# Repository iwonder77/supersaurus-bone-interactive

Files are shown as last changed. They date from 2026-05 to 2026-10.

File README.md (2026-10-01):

# Supersaurus Bone Interactive

Three-channel 555 monostable timer board driving RGB LED strips for a guess-the-dinosaur-bone exhibit at Thanksgiving Point's Museum of Ancient Life.

https://github.com/user-attachments/assets/5193e17a-1725-41bf-98e3-4b2cfe211b8b

---

## At a Glance

| | |
| --- | --- |
| **Supply** | 12 V DC, single rail |
| **Channels** | 3 (one per answer slot) |
| **Input per channel**  | Littlefuse reed switch (slot occupancy) AND master pushbutton |
| **Output pulse width** | `~3.63s` - set by R`33k` / C`100uF` |
| **Load per channel** | 12V RGB LED strip, 1.67 A measured |
| **Load switching** | Off-board N-channel MOSFET module, low-side |
| **PCB** | `2-layer, 1 oz copper, HASL, 1.6 mm` |
| **Assembly** | `JLCPCB Assembly and hand soldered` |
| **Active logic** | Trigger is active-LOW; LED output is active-HIGH |

---

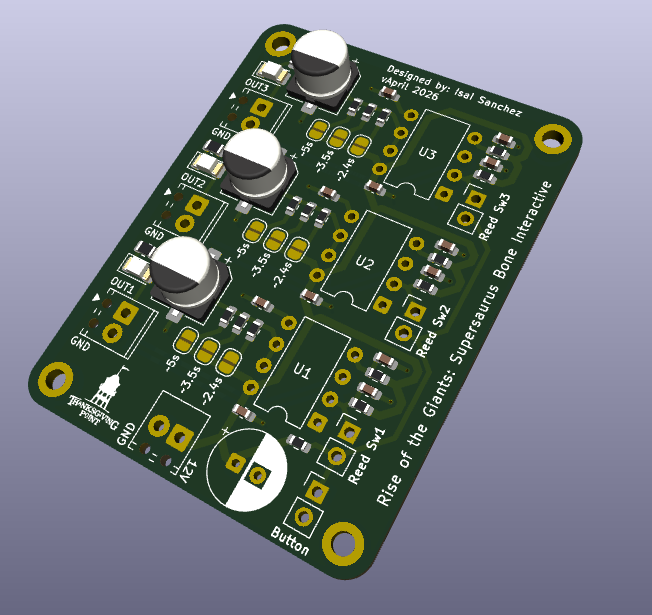
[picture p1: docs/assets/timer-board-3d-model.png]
3d PCB Model


## Overview

The Supersaurus bone interactive at Thanksgiving Point's Museum of Ancient Life invites visitors to guess which dinosaur the Supersaurus is related to based solely on scapula bone graphics. Guests place the Supersaurus scapula into one of three slots, each corresponding to a different dinosaur with its own scapula graphic. When they're ready to check their answer, they press a button, and an LED light strip installed behind the frosted acrylic slots briefly lights up red or green, providing immediate feedback on their guess.

When presented with the requirements of this project, my mind immediately jumped to using basic GPIO pins on a microcontroller to read the inputs, debounce them in software, and trigger a switching module for the lights. Even though that may have worked, removing software entirely for a three-input interaction with fixed timing removes an entire set of failure modes. A discrete analog implementation has no boot time, no watchdog to tune, and no flash to corrupt on abrupt power loss.

## Hardware Design Requirements

The interactive needed a circuit that:

- Debounces reed switch + button inputs for a smooth user experience
- Triggers immediate feedback on their answer for a short duration
- Resets the system quickly to not spoil the answer for the next guest
- Draws minimal power to handle reliable long term operation (next to 0 maintenance on parts)

These requirements quickly led to using a 555 timer in monostable mode to handle the timing portion of the interactive, and a MOSFET circuit to handle the fast and power efficient switching of a higher current load (LED strips).

## Main Hardware Components

- T.I. NE555P Timer ([datasheet](https://www.ti.com/lit/ds/symlink/ne555.pdf?ts=1777883502652))
- IRF520 MOSFET ([datasheet](https://www.vishay.com/docs/91017/irf520.pdf))
- PWM RGB LED Strips [link](https://www.amazon.com/dp/B0FSWXXXD4?ref=fed_asin_title&th=1)

The full BOM is included in the `manufacturing/` folder

## Full Schematic

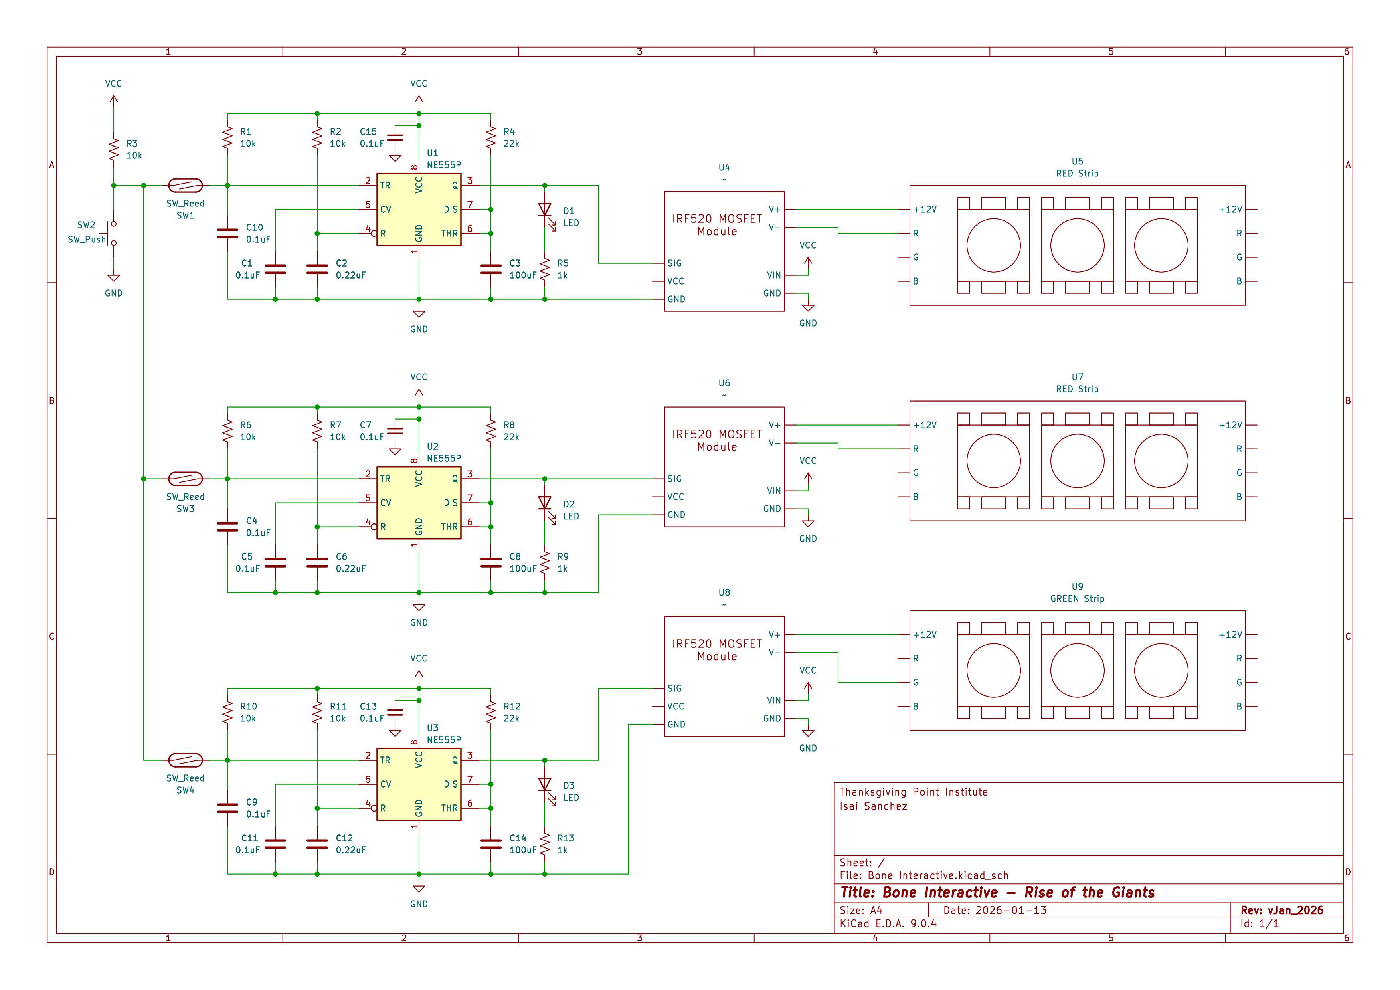
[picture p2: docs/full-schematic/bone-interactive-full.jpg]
full schematic


## Main Hardware Architecture

Each 555 timer's TRIG pin is connected to a single reed switch (mounted behind the slot guests put the bone in), and each reed switch feeds into one "master" N.O. button. RC/pull up networks are configured for each TRIG pin to ensure smooth and predictable switching. This configuration allows the TRIG pin on each 555 timer to be pulled LOW only when its corresponding reed switch is closed **and** the button is pressed.

The three 555 timers are used in monostable mode to output a short pulse signal on pin Q when the TRIG pin is pulled low. More on monostable mode and the duration of the pulse below. The output signal (~10.3V when VCC = 12V) is fed into the gate of a IRF520 N-channel MOSFET module, which switches the low side of an RGB LED Strip for as long as the gate is driven.

## 555 Timer Notes

### Monostable Mode

Shorting the DISCHARGE and THRESHOLD pins of the 555 timer and routing them to an RC circuit operates the 555 timer in monostable mode. Ben Eater has a really great and informative series on the different 555 timer modes, I highly recommend watching them. Here's the one about [monostable mode](https://www.youtube.com/watch?v=81BgFhm2vz8).

In any case, the formula for the output signal duration is

$$
t_w = 1.1 \times R_A \times C
$$

Where $R_A$ and $C$ are the values of the resistor and capacitor. For future boards I wanted to make this duration configurable by having three open jumpers routed to resistors of different values (22k, 33k, 47k). The output pulse duration would change depending on which jumper is soldered.

Note: the trigger pulse must be shorter than $t_w$ and below $\frac{1}{3}V_{CC}$ (the 555's internal comparator threshold). If TRIG remains below $\frac{1}{3}V_{CC}$ beyond $t_w$, the output holds HIGH until TRIG rises.

### Power-on Reset Circuit

The 0.22uF and 10k RC network on the 555's RESET pin form a POR (power-on reset) circuit. During initial power-up testing without it, the output (Q) pin produced occasional HIGH pulses due to undefined internal states of the IC, which turned on downstream LED strips. This RC network briefly holds RESET low during power-up, forcing Q in a known LOW state while internal circuitry stabilizes. As the 0.22uF capacitor charges, RESET rises to VCC and normal operation begins, preventing false triggering at startup.

### Output (Q) Voltage

When triggered, the output voltage on pin Q isn't necessarily equal to VCC. When powered by 5V, I measured outputs of ~3.3V. When powered by 12V, I measured outputs of ~10.3V. The datasheet confirms this slight drop in voltage, and it is important to know since we'll be using it to drive the gate of an N-Channel MOSFET.

## MOSFET Selection and Gate Drive Design Notes

### Role

The main design requirements that guided my MOSFET selection were the following

- Fast switch times of 12V RGB LED strip loads (on the order of 1-2A)
- Minimal power dissipation
- Predictable operating behavior

Although quite outdated, the IRF520 N-Channel MOSFET was initially selected due to its accessibility, very low cost, and basic matching of electrical characteristics to the requirements described above (more on these below).

### Initial Implementation and Failure Mode

My initial prototype powered the 555 timer at VCC = 5V and used the output (Q) pin to directly drive the gate of an IRF520 MOSFET module. While the timing circuit functioned correctly, the LED strip failed to illuminate properly. This failure mode was not due to wiring or logic errors, but rather improper gate drive conditions for the selected MOSFET.

I'll start off by describing the important electrical characteristics we should know about for this design (for a deeper dive, refer to the [datasheet](https://www.vishay.com/docs/91017/irf520.pdf)). Then I'll discuss the proper gate drive design.

### Key Electrical Considerations

#### 1. $V_{GS(th)}$ Gate-Source Threshold Voltage

$V_{GS(th)} = 2.0\,\text{V}$ to $4.0\,\text{V}$ at $I_D = 250\,\mu\text{A}$

This parameter defines the voltage at which the MOSFET just barely begins to conduct a very small current - it is **not** an operating point for driving the gate and turning on the MOSFET. The best design drives the gate well past this threshold simply due to the fact that at higher gate voltages, the resistance between the drain-source ($R_{DS(on)}$) is much lower, leading to more efficient power operation.

#### 2. $R_{DS(on)}$ Drain-Source "on" Resistance

$R_{DS(on)} = 0.27\,\Omega$ at $V_{GS} = 10\,\text{V}$

For switching applications, the MOSFET must operate in the **ohmic (linear) region** (the $I_D$ vs. $V_{DS}$ graph below shows this region for various $V_{GS}$ curves) with as low a $R_{DS(on)}$ as possible. The lower the resistance, the less power is dissipated. To reach this lower resistance, we must drive the gate further and further from the threshold voltage (but don't exceed its maximum).

#### 3. $I_D$ vs. $V_{DS}$ graph at T = 25C (from datasheet)

<div align="center">
    <image src="docs/assets/ID-vs-VDS-curve.png" alt="id-vs-vds-curve">
</div>

In the ohmic region (linear region of the curves) the MOSFET acts like a voltage controlled resistor, where

$$
I_D = \frac{V_{DS}}{R_{DS(on)}}
$$

note that $R_{DS(on)}$ is not a fixed quantity, but decreases as $V_{GS}$ rises above $V_{GS(th)}$. The datasheet value of $0.27\,\Omega$ only holds at $V_{GS} = 10V$. Near the threshold voltage, it can be orders of magnitude higher, which directly increases power drawn ($P = I^2 * R$). Otherwise, in the saturation region, the MOSFET essentially acts as a current source, due to how the drain current $I_D$ stays nearly constant regardless of $V_{DS}$.

### Gate Drive Design

With the 555 timer powered at 5V, the output pin's HIGH voltage falls between 2.75V-3.3V (datasheet values). This is exactly in the MOSFET's $V_{GS(th)}$ range, where it barely starts to open and conduct current. Suppose our timer drove the gate at 3.3V, this would be a huge reliability concern, because:

- If the specific MOSFET we used had a $V_{GS(th)}$ = 2V: the MOSFET would slightly conduct
- If the MOSFET had a $V_{GS(th)}$ = 3.3V: the MOSFET would be right at threshold — essentially off
- If the MOSFET had a $V_{GS(th)}$ = 4V: the MOSFET wouldn't conduct at all

This doesn't even consider the inefficient power operation of the MOSFET in these conditions due to the very high $R_{DS(on)}$ and the 12V LED strip load demand. To ensure proper MOSFET operation, the gate drive voltage must be increased to a level where $R_{DS(on)}$ is low and well-defined.

Two viable approaches were considered:

#### Option 1: Use a Logic-Level MOSFET (IRLZ44N) with 5V supply for 555 timers

- Pros: compatible with lower level logic
- Cons: complicates power architecture (12V for LED strips and 5V for 555 timers)

#### Option 2: Increase Gate Drive Voltage (Selected)

Power the 555 timers at 12V (note: 5V sits at the lower bound of the NE555's recommended operating range, we should have started prototyping here). This results in:

- A gate drive voltage of ~10.3V
- A fully enhanced ("on") IRF520 with much lower $R_{DS(on)}$ and more manageable power dissipation
- A single 12V supply for the entire system

### Final Operating Behavior Calculations

Each LED strip draws 1.67A at 12V, measured directly on the bench. With the 555 timers powered at VCC = 12V, the gate sees ~10.3V - close to the datasheet condition of $V_{GS} = 10\text{V}$, so $R_{DS(on)} = 0.27\Omega$ applies directly.

The voltage drop across the MOSFET when fully on is

$$
V_{DS} = I_D \times R_{DS(on)} = 1.67\text{A} \times 0.27\Omega \approx 0.45\text{V}
$$

This confirms the MOSFET is in the ohmic region: ohmic operation requires $V_{DS} < V_{GS} - V_{GS(th)}$, and $0.45\text{V} \ll 10\text{V} - 2\text{V} = 8\text{V}$. The power dissipated by the MOSFET is then:

$$
P = I_D^2 \times R_{DS(on)} = (1.67\text{A})^2 \times 0.27\Omega \approx 0.75\text{W}
$$

At 0.75W, the IRF520 in its TO-220 package dissipates comfortably without a heatsink - a viable operating point for this application.

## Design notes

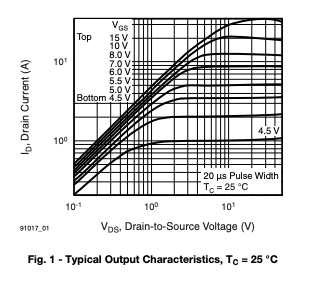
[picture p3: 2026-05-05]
docs/assets/ID-vs-VDS-curve.png

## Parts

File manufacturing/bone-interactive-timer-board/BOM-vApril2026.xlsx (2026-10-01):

Comment | Reference Designator | Footprint | JLCPCB Part #
0.1uF | C1, C2, C5, C6, C8, C9, C11, C13, C14 | Capacitor_SMD:C_0603_1608Metric | C14663
0.22uF | C3, C7, C12 | Capacitor_SMD:C_0603_1608Metric | C21120
100uF | C4, C10, C15 | Capacitor_SMD:CP_Elec_6.3x5.4 | C2886300
GREEN LED | D1, D2, D3 | LED_SMD:LED_1206_3216Metric | C364563
10k | R1, R2, R4, R5, R10, R14, R15 | Resistor_SMD:R_0603_1608Metric | C99198
1k | R3, R6, R16 | Resistor_SMD:R_0805_2012Metric | C17513
22k | R7, R11, R17 | Resistor_SMD:R_0603_1608Metric | C31850
33k | R8, R12, R18 | Resistor_SMD:R_0603_1608Metric | C4216
47k | R9, R13, R19 | Resistor_SMD:R_0603_1608Metric | C25819

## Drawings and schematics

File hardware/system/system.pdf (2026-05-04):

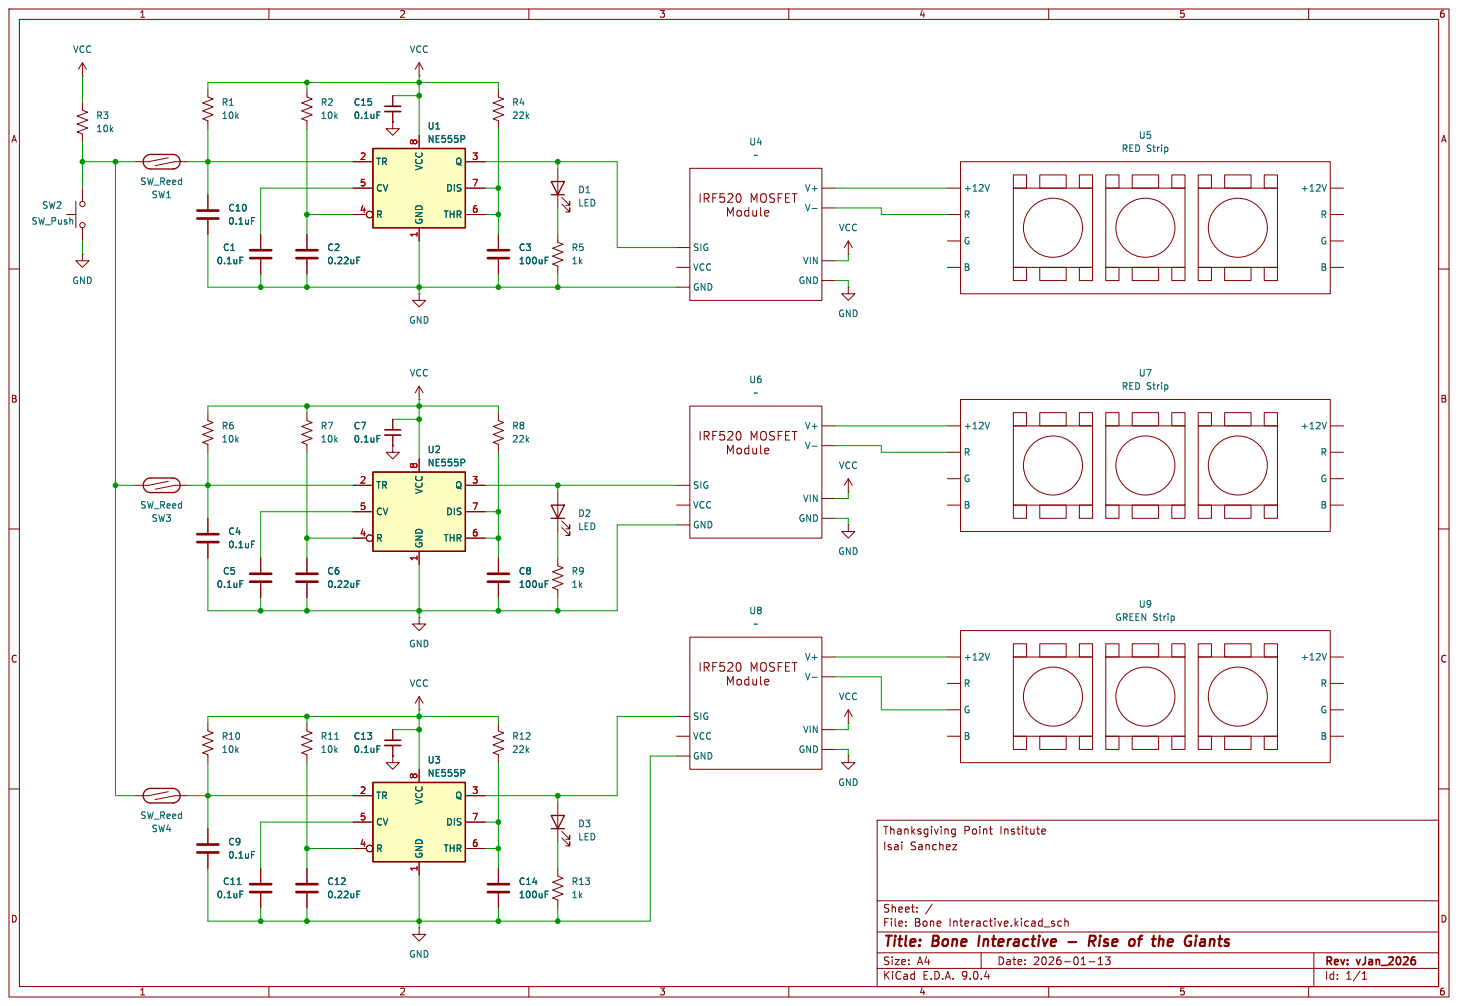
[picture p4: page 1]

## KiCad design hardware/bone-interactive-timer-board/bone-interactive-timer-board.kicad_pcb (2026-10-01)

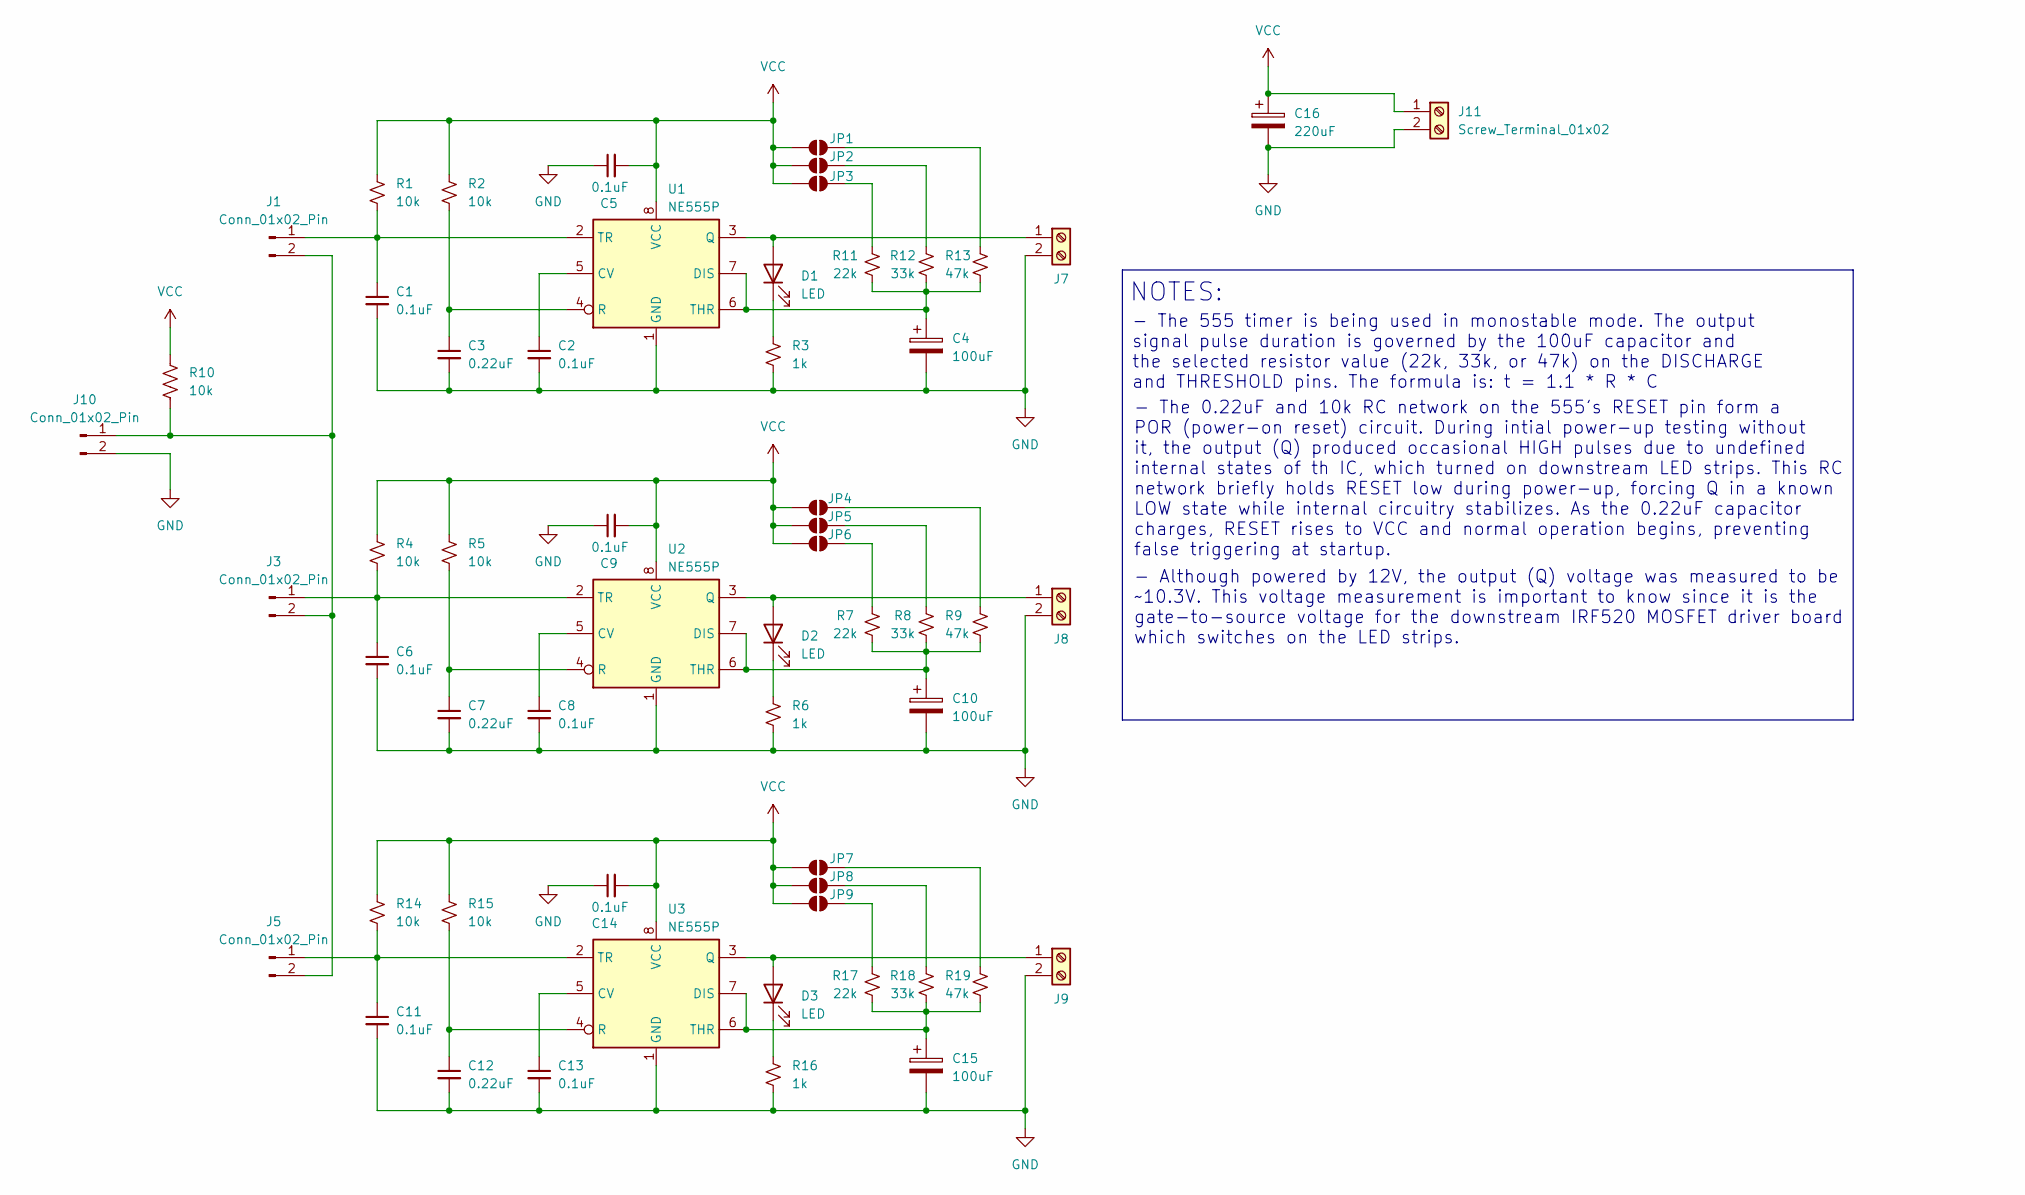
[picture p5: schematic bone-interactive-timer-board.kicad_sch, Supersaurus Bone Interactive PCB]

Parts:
C1, C2, C5, C6, C8, C9, C11, C13, C14: 0.1uF; C_0603_1608Metric
C3, C7, C12: 0.22uF; C_0603_1608Metric
C4, C10, C15: 100uF; CP_Elec_6.3x5.4
C16: 220uF; CP_Radial_D7.5mm_P2.50mm
D1, D2, D3: LED; LED_1206_3216Metric
J1, J3, J5, J10: Conn_01x02_Pin; PinHeader_1x02_P2.54mm_Vertical
J7, J8, J9, J11: Screw_Terminal_01x02; TerminalBlock_Phoenix_MPT-0,5-2-2.54_1x02_P2.54mm_Horizontal
JP1, JP2, JP3, JP4, JP5, JP6, JP7, JP8, JP9: SolderJumper_2_Open; SolderJumper-2_P1.3mm_Open_RoundedPad1.0x1.5mm
R1, R2, R4, R5, R10, R14, R15: 10k; R_0603_1608Metric
R3, R6, R16: 1k; R_0805_2012Metric
R7, R11, R17: 22k; R_0603_1608Metric
R8, R12, R18: 33k; R_0603_1608Metric
R9, R13, R19: 47k; R_0603_1608Metric
U1, U2, U3: NE555P; DIP-8_W7.62mm

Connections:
GND: C1.2, C2.2, C3.2, C4.2, C5.1, C6.2, C7.2, C8.2, C9.1, C10.2, C11.2, C12.2, C13.2, C14.1, C15.2, C16.2, J7.2, J8.2, J9.2, J10.2, J11.2, R3.1, R6.1, R16.1, U1.1 (GND), U2.1 (GND), U3.1 (GND)
unnamed: D1.2 (A), J7.1, U1.3 (Q)
unnamed: D1.1 (K), R3.2
unnamed: D2.2 (A), J8.1, U2.3 (Q)
unnamed: D2.1 (K), R6.2
unnamed: D3.2 (A), J9.1, U3.3 (Q)
unnamed: D3.1 (K), R16.2
unnamed: C1.1, J1.1, R1.2, U1.2 (TR)
unnamed: J1.2, J3.2, J5.2, J10.1, R10.2
unnamed: C6.1, J3.1, R4.2, U2.2 (TR)
unnamed: C11.1, J5.1, R14.2, U3.2 (TR)
unnamed: JP1.2 (B), R13.2
unnamed: JP2.2 (B), R12.1
unnamed: JP3.2 (B), R11.2
unnamed: JP4.2 (B), R9.2
unnamed: JP5.2 (B), R8.1
unnamed: JP6.2 (B), R7.2
unnamed: JP7.2 (B), R19.2
unnamed: JP8.2 (B), R18.1
unnamed: JP9.2 (B), R17.2
unnamed: C2.1, U1.5 (CV)
unnamed: C4.1, R11.1, R12.2, R13.1, U1.6 (THR), U1.7 (DIS)
unnamed: C3.1, R2.2, U1.4 (R)
unnamed: C8.1, U2.5 (CV)
unnamed: C10.1, R7.1, R8.2, R9.1, U2.6 (THR), U2.7 (DIS)
unnamed: C7.1, R5.2, U2.4 (R)
unnamed: C13.1, U3.5 (CV)
unnamed: C15.1, R17.1, R18.2, R19.1, U3.6 (THR), U3.7 (DIS)
unnamed: C12.1, R15.2, U3.4 (R)
VCC: C5.2, C9.2, C14.2, C16.1, J11.1, JP1.1 (A), JP2.1 (A), JP3.1 (A), JP4.1 (A), JP5.1 (A), JP6.1 (A), JP7.1 (A), JP8.1 (A), JP9.1 (A), R1.1, R2.1, R4.1, R5.1, R10.1, R14.1, R15.1, U1.8 (VCC), U2.8 (VCC), U3.8 (VCC)

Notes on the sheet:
- Although powered by 12V, the output (Q) voltage was measured to be ~10.3V. This voltage measurement is important to know since it is the gate-to-source voltage for the downstream IRF520 MOSFET driver board which switches on the LED strips.
NOTES:
- The 555 timer is being used in monostable mode. The output signal pulse duration is governed by the 100uF capacitor and the selected resistor value (22k, 33k, or 47k) on the DISCHARGE and THRESHOLD pins. The formula is: t = 1.1 * R * C
- The 0.22uF and 10k RC network on the 555's RESET pin form a POR (power-on reset) circuit. During intial power-up testing without it, the output (Q) produced occasional HIGH pulses due to undefined internal states of th IC, which turned on downstream LED strips. This RC network briefly holds RESET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

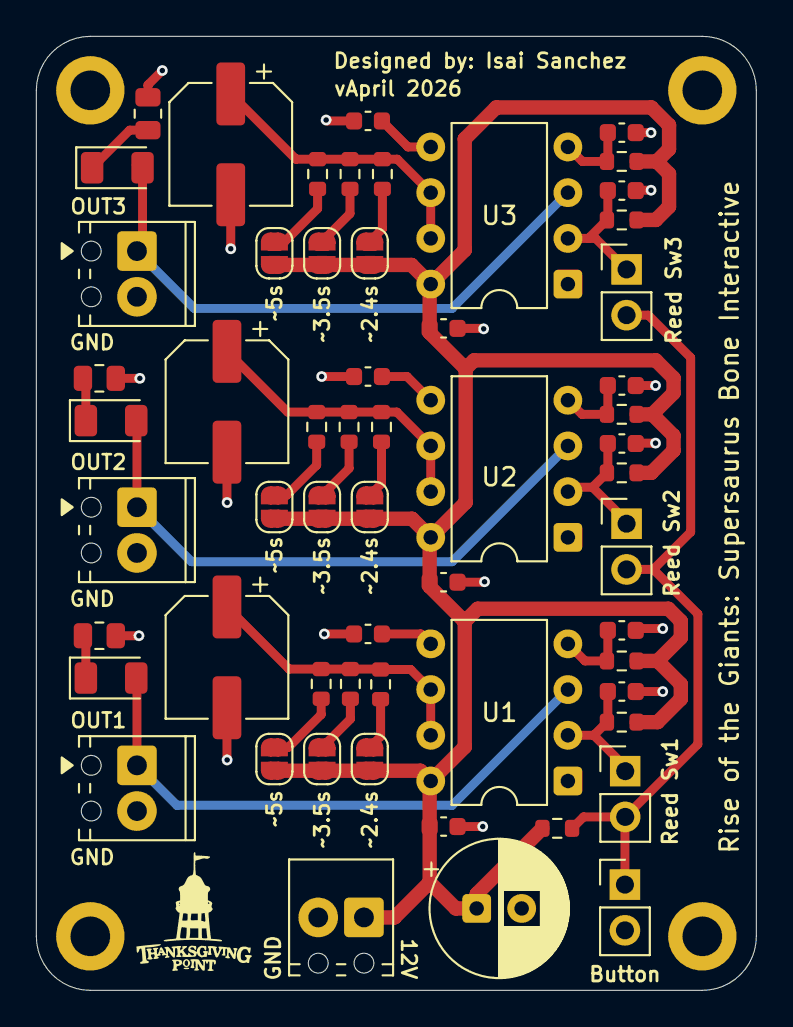
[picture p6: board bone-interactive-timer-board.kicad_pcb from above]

Board: 2 copper layers, 40.0 x 53.0 mm, 58 parts (0 on the bottom side), 30 nets.

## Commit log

2026-05-04 added main hardware list and full schematic
2026-05-04 fix path to full schematic file
2026-05-05 add relevant notes about 555 timer
2026-05-05 add initial IRF520 N-channel MOSFET notes
2026-05-05 add explanation why we can't drive the gate with near logic-level voltages
2026-05-05 fix structure of MOSFET notes
2026-05-05 clean up section where explanation on why MOSFET being driven by 3.3v at the gate is not ideal at all
2026-05-05 add final edits before revamped MOSFET selection section
2026-05-05 restructure mosfet section
2026-05-07 cleaning up MOSFET section
2026-10-01 feat: restructuring this repo starting with hardware folder to hold kicad files
    [bone-interactive-timer-board.kicad_pcb, bone-interactive-timer-board.kicad_sch]
2026-10-01 feat: adding .gitignore file for Kicad specific files to ignore
2026-10-01 style: renaming kicad project
    [bone-interactive-timer-board.kicad_pcb, bone-interactive-timer-board.kicad_sch]
2026-10-01 feat: added system folder to hold entire system kicad files (timer board + MOSFET board + led strips + reed switches wiring)
    [system.kicad_pcb, system.kicad_sch]
2026-10-01 feat: added BOM, CPL, and Gerber zip files for bone interactive timer board
    [BOM-vApril2026.xlsx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]
2026-10-01 fix: small addition to kicad files to ignore
2026-10-01 style: save updated files to new version
    [system.kicad_sch]
2026-10-01 feat: added 3d model png of board
